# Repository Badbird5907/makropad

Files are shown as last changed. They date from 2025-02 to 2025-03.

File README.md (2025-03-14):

# Makropad

Makropad is my attempt at a custom macropad, inspired by the [Stream Deck Plus](https://www.elgato.com/ca/en/p/stream-deck-plus-black).
It uses Kaith Choc v2 switches, 2 encoders, powered by a RP2040.

A user-friendly BOM can be found [here](https://github.com/Badbird5907/makropad/blob/master/PCB/BOM.md)

## Features
- 2 rotary encoders
- 10 backlit keys
- 128x32 OLED display

## Screenshots
Case

Schematic

PCB

3D Renders of the Cherry MX switch version (made with Shapr3D):

Shapr Image-2025-02-09 170116

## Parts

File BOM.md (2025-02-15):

# Makropad BOM

| Quantity | Component Description |
|---|---|
| 10x | Kailh choc v2 switches (or any other choc v2 switch) |
| 10x | Reverse-mounted SK6812MINI-E SMD LEDs |
| 12x | SMD Diodes (1N4148W) |
| 6x | Normal front-mounted SK6812-MINI SMD LEDs (SK6812mini-012) |
| 2x | EC11 Rotary encoders |
| 1x | 0.91" OLED display |
| 1x | Seeed Studio XIAO RP2040 |
| 6x | 10kΩ SMD 1206 resistors |
| 16x | 100nF SMD 1206 capacitors |
| 1x | PCF8574A I2C I/O expander |
| 5x | M3 hex nuts |
| 5x | M3x5mx4mm heatset inserts |
| 5x | M3x16mm screws |

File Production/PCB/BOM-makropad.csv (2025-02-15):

Comment | Designator | Footprint | LCSC | Quantity
RotaryEncoder_Switch | SW11 | encoder | C143788 | 1
10k | R1,R2 | R_1206_3216Metric | C17902 | 2
0.1uF | C1,C10,C11,C12,C13,C14,C15,C16,C2,C3,C4,C5,C6,C7,C8,C9 | C_1206_3216Metric | C24497 | 16
SK6812 | D23,D24,D25,D26,D27,D28 | LED_SK6812MINI_PLCC4_3.5x3.5mm_P1.75mm | C2886570 | 6
D | D1,D10,D11,D12,D2,D3,D4,D5,D6,D7,D8,D9 | D_SOD-123 | C81598 | 12
PCF8574A | U1 | SOIC127P1032X265-16N | C86832 | 1
SW_Push_45deg | SW4 | SW_Kailh_Choc_V2 |  | 1
SW_Push_45deg | SW10 | SW_Kailh_Choc_V2 |  | 1
SW_Push_45deg | SW1 | SW_Kailh_Choc_V2 |  | 1
OLED_DISPLAY | J1 | SSD1306-0.91-OLED-4pin-128x32 |  | 1
RotaryEncoder_Switch | SW12 | encoder |  | 1
SW_Push_45deg | SW6 | SW_Kailh_Choc_V2 |  | 1
SW_Push_45deg | SW2 | SW_Kailh_Choc_V2 |  | 1
SW_Push_45deg | SW7 | SW_Kailh_Choc_V2 |  | 1
SW_Push_45deg | SW5 | SW_Kailh_Choc_V2 |  | 1
SW_Push_45deg | SW8 | SW_Kailh_Choc_V2 |  | 1
Conn_01x04 | J2 | 4pin |  | 1
SW_Push_45deg | SW3 | SW_Kailh_Choc_V2 |  | 1
SW_Push_45deg | SW9 | SW_Kailh_Choc_V2 |  | 1
SK6812 | D19 | SK6812MINI-E |  | 1
SK6812 | D21 | SK6812MINI-E |  | 1
SK6812 | D16 | SK6812MINI-E |  | 1
SK6812 | D20 | SK6812MINI-E |  | 1
SK6812 | D18 | SK6812MINI-E |  | 1
SK6812 | D14 | SK6812MINI-E |  | 1
SK6812 | D13 | SK6812MINI-E |  | 1
SK6812 | D17 | SK6812MINI-E |  | 1
SK6812 | D15 | SK6812MINI-E |  | 1
MOUDLE-SEEEDUINO-XIAO | U2 | XIAO-Generic-Hybrid-14P-2.54-21X17.8MM |  | 1
SK6812 | D22 | SK6812MINI-E |  | 1

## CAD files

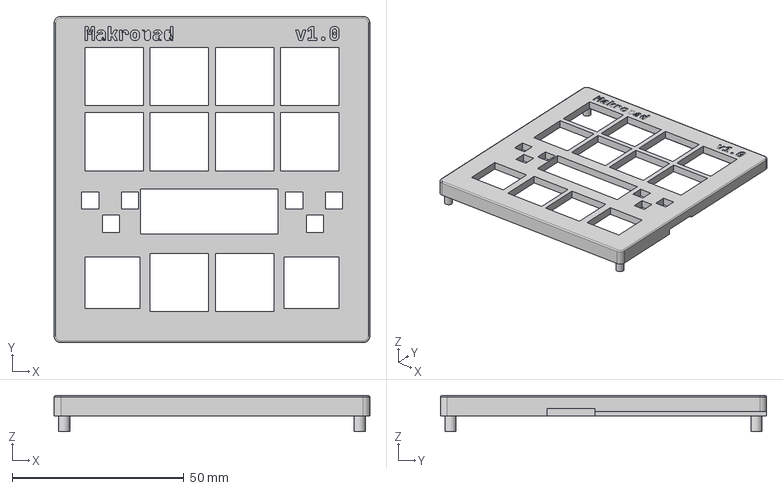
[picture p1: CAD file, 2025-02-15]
CAD/top.step
92.0 x 95.0 x 10.5 mm

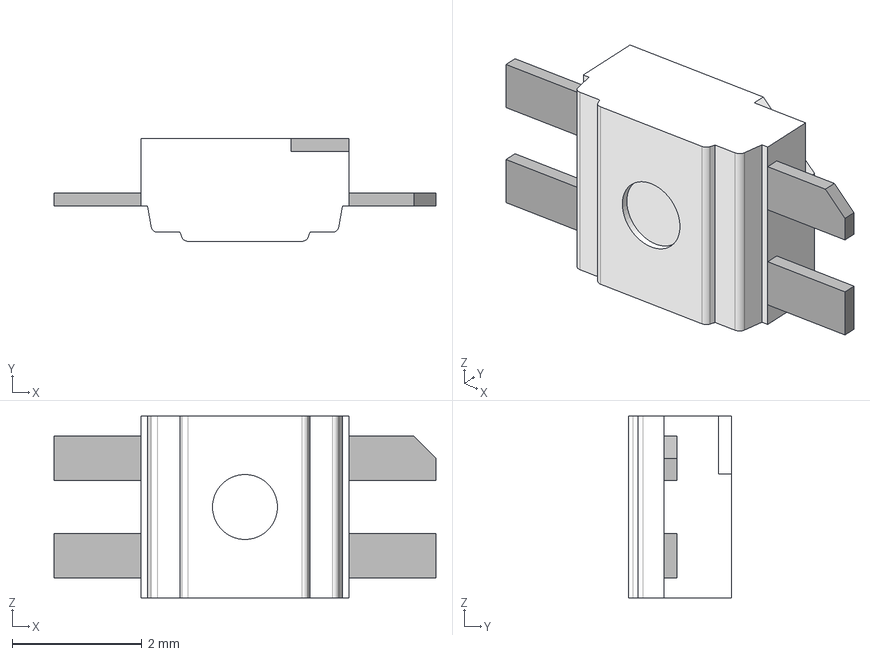
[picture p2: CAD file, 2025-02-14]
PCB/Components/neopixel.petty/SK6812MINI-E.step
5.88 x 1.58 x 2.80 mm

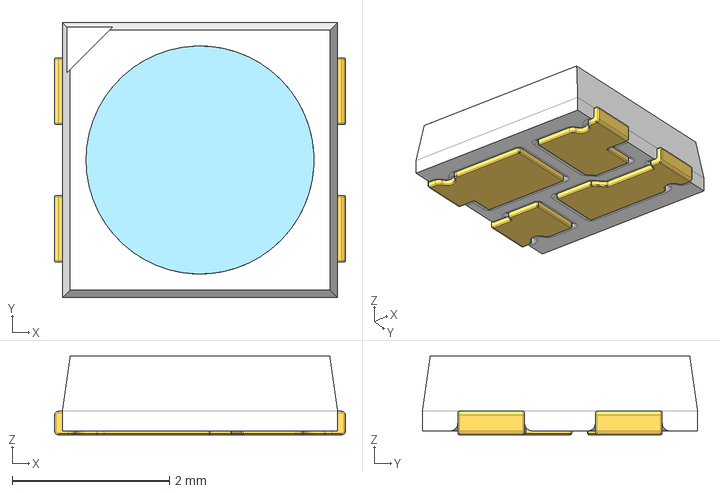
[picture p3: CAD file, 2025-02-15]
PCB/Components/SK6812_FRONT.stp
3.70 x 3.50 x 1.00 mm

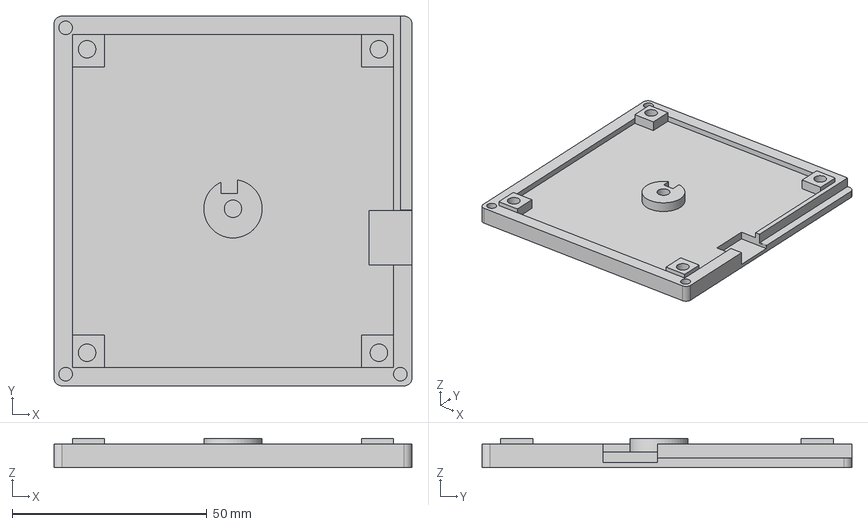
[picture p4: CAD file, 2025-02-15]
Production/3D Print/bottom.step
92.0 x 95.0 x 7.50 mm

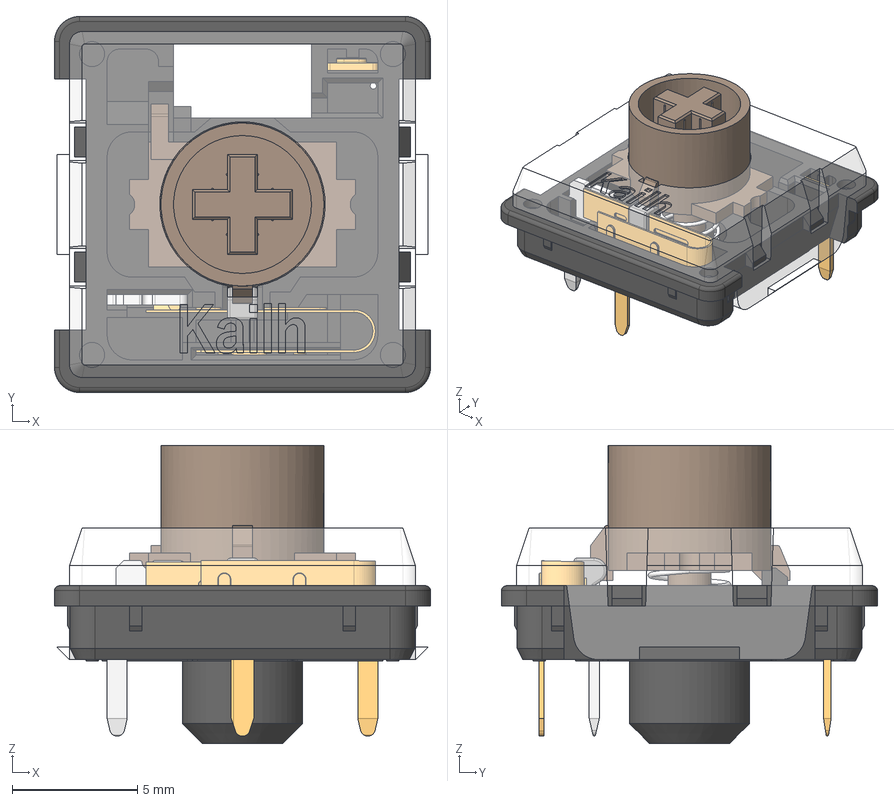
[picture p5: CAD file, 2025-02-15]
PCB/Components/choc-brown.step
15.0 x 15.0 x 11.9 mm
bottom
contact
top
stem_tactile
pin1
pin2
pin3
shrunken_spring

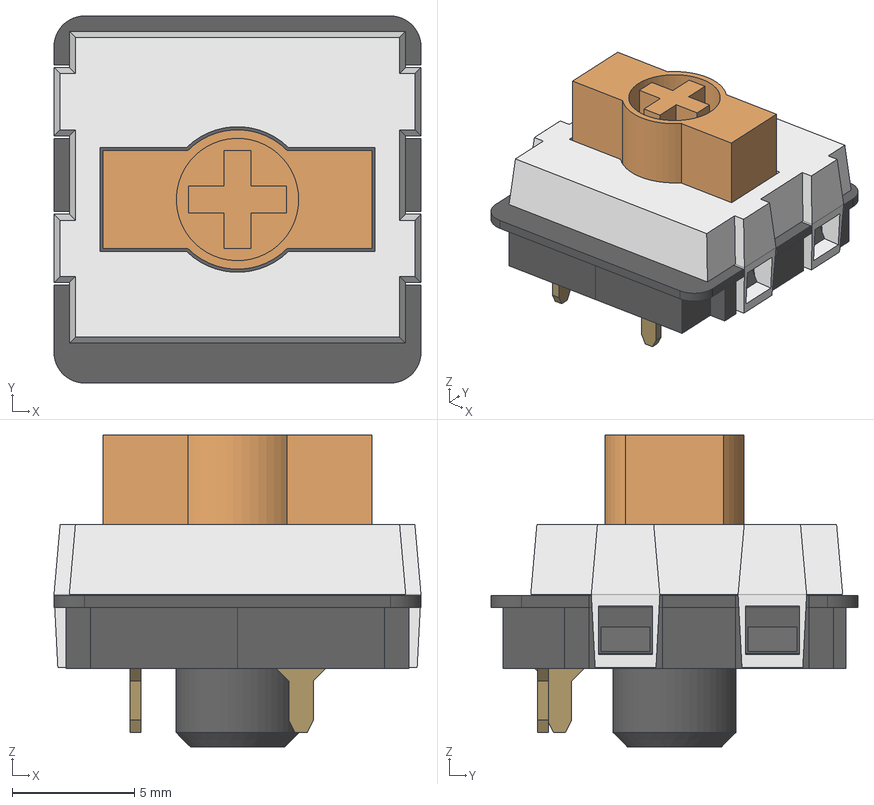
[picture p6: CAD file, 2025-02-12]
PCB/Components/Gateron KS-33.step
15.0 x 15.0 x 12.8 mm
Base
Stem
Cap
PinA
PinB

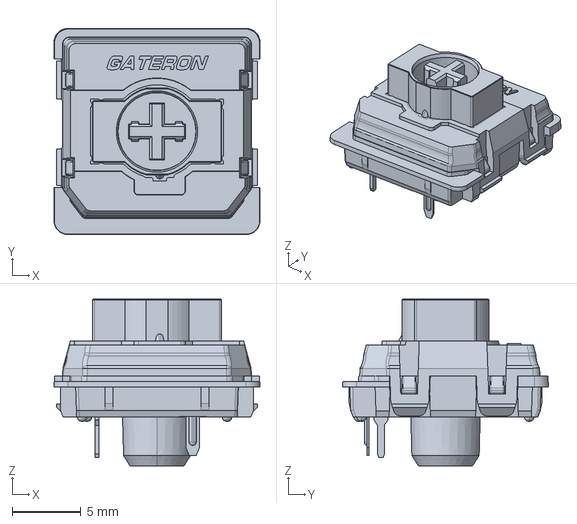
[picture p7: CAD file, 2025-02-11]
PCB/Components/Gateron Low Profile Switch 2.0.stp
15.0 x 15.0 x 12.1 mm

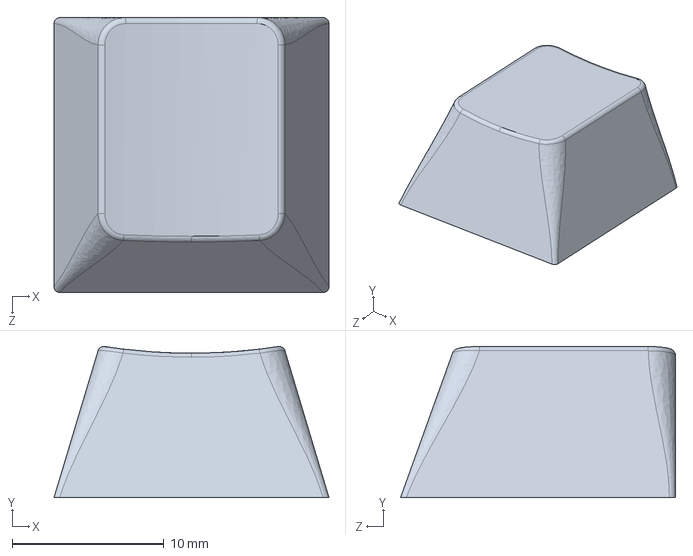
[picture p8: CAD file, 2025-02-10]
PCB/Components/r1_100.STEP
18.1 x 9.95 x 18.1 mm

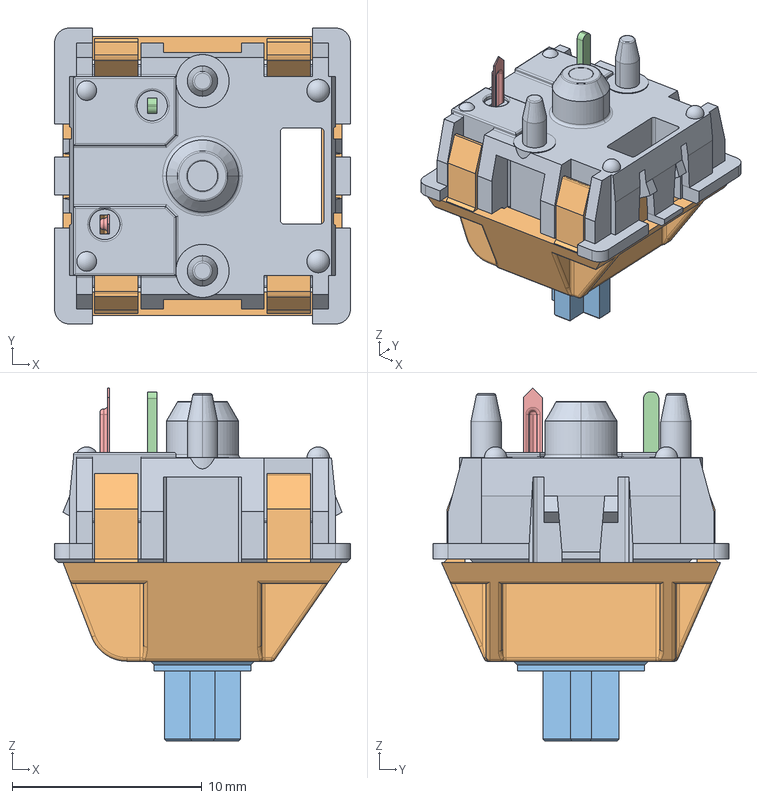
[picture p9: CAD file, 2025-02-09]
PCB/Components/CherryMX.stp
15.6 x 15.6 x 18.6 mm
MX_DOWN
MX_UP
UP_MX
MX_PIN
MX_SPRING
MX_CLICK

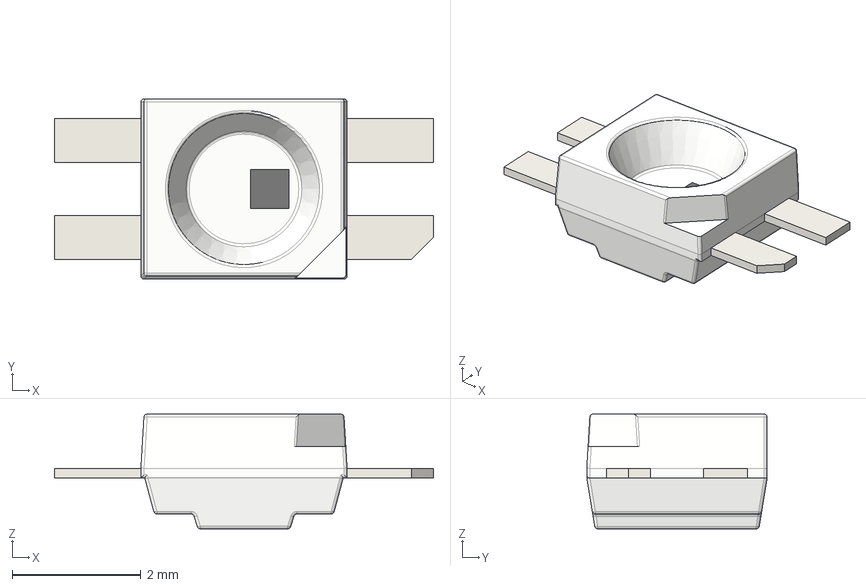
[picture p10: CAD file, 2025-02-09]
PCB/Components/LED_SK6812MINI-E.step
5.88 x 2.80 x 1.78 mm

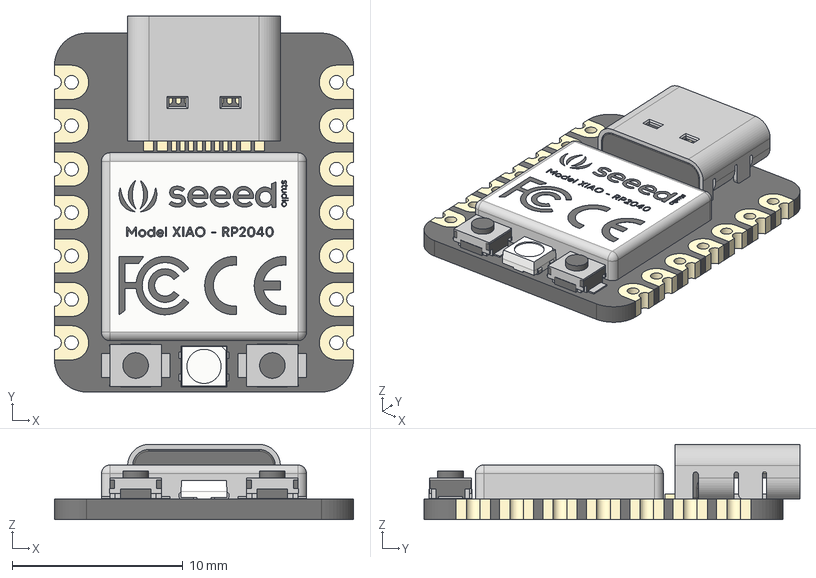
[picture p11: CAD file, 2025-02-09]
PCB/Components/Seeed Studio XIAO RP2040 v26.step
17.5 x 22.0 x 4.40 mm
type-c v2
smd_button v3
DOUT
DIN
VSS
VDD
smd_button v3(Mirror)

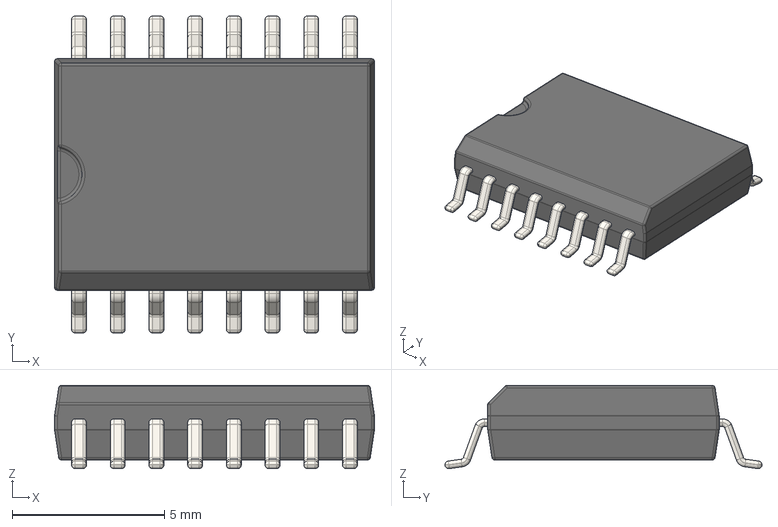
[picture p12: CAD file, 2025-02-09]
PCB/Components/SOT162-1.step
10.5 x 10.4 x 2.73 mm

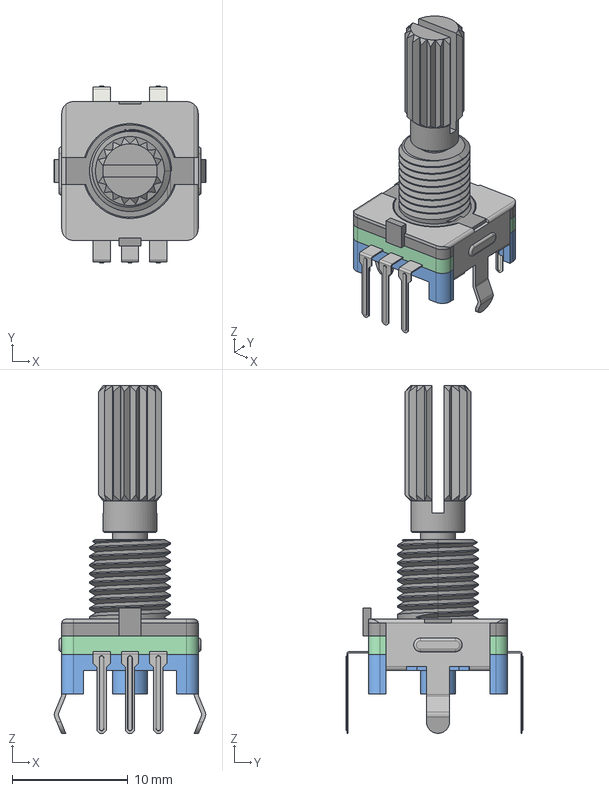
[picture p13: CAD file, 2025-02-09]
PCB/Components/EC11_Rotary_Encoder_Switched.step
13.1 x 15.3 x 30.1 mm

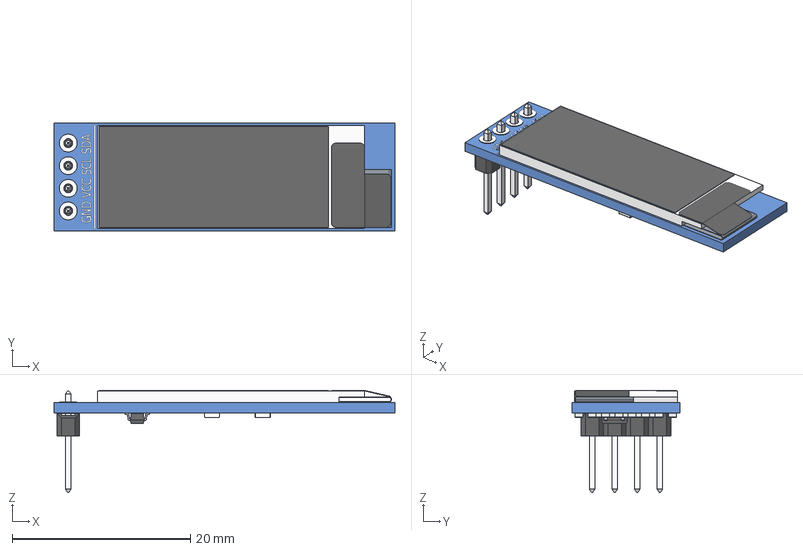
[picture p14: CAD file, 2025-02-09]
PCB/Components/OLED_0.91_128x32.stp
38.3 x 12.1 x 11.5 mm
OLED_0.91_128x32
Pin Header 4 x 1 TH 2.54mm Pitch
RESC-0603 x 13
2SD0601A

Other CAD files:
PCB/Components/N0016A.stp
PCB/Components/PCF8574A_SMD.step

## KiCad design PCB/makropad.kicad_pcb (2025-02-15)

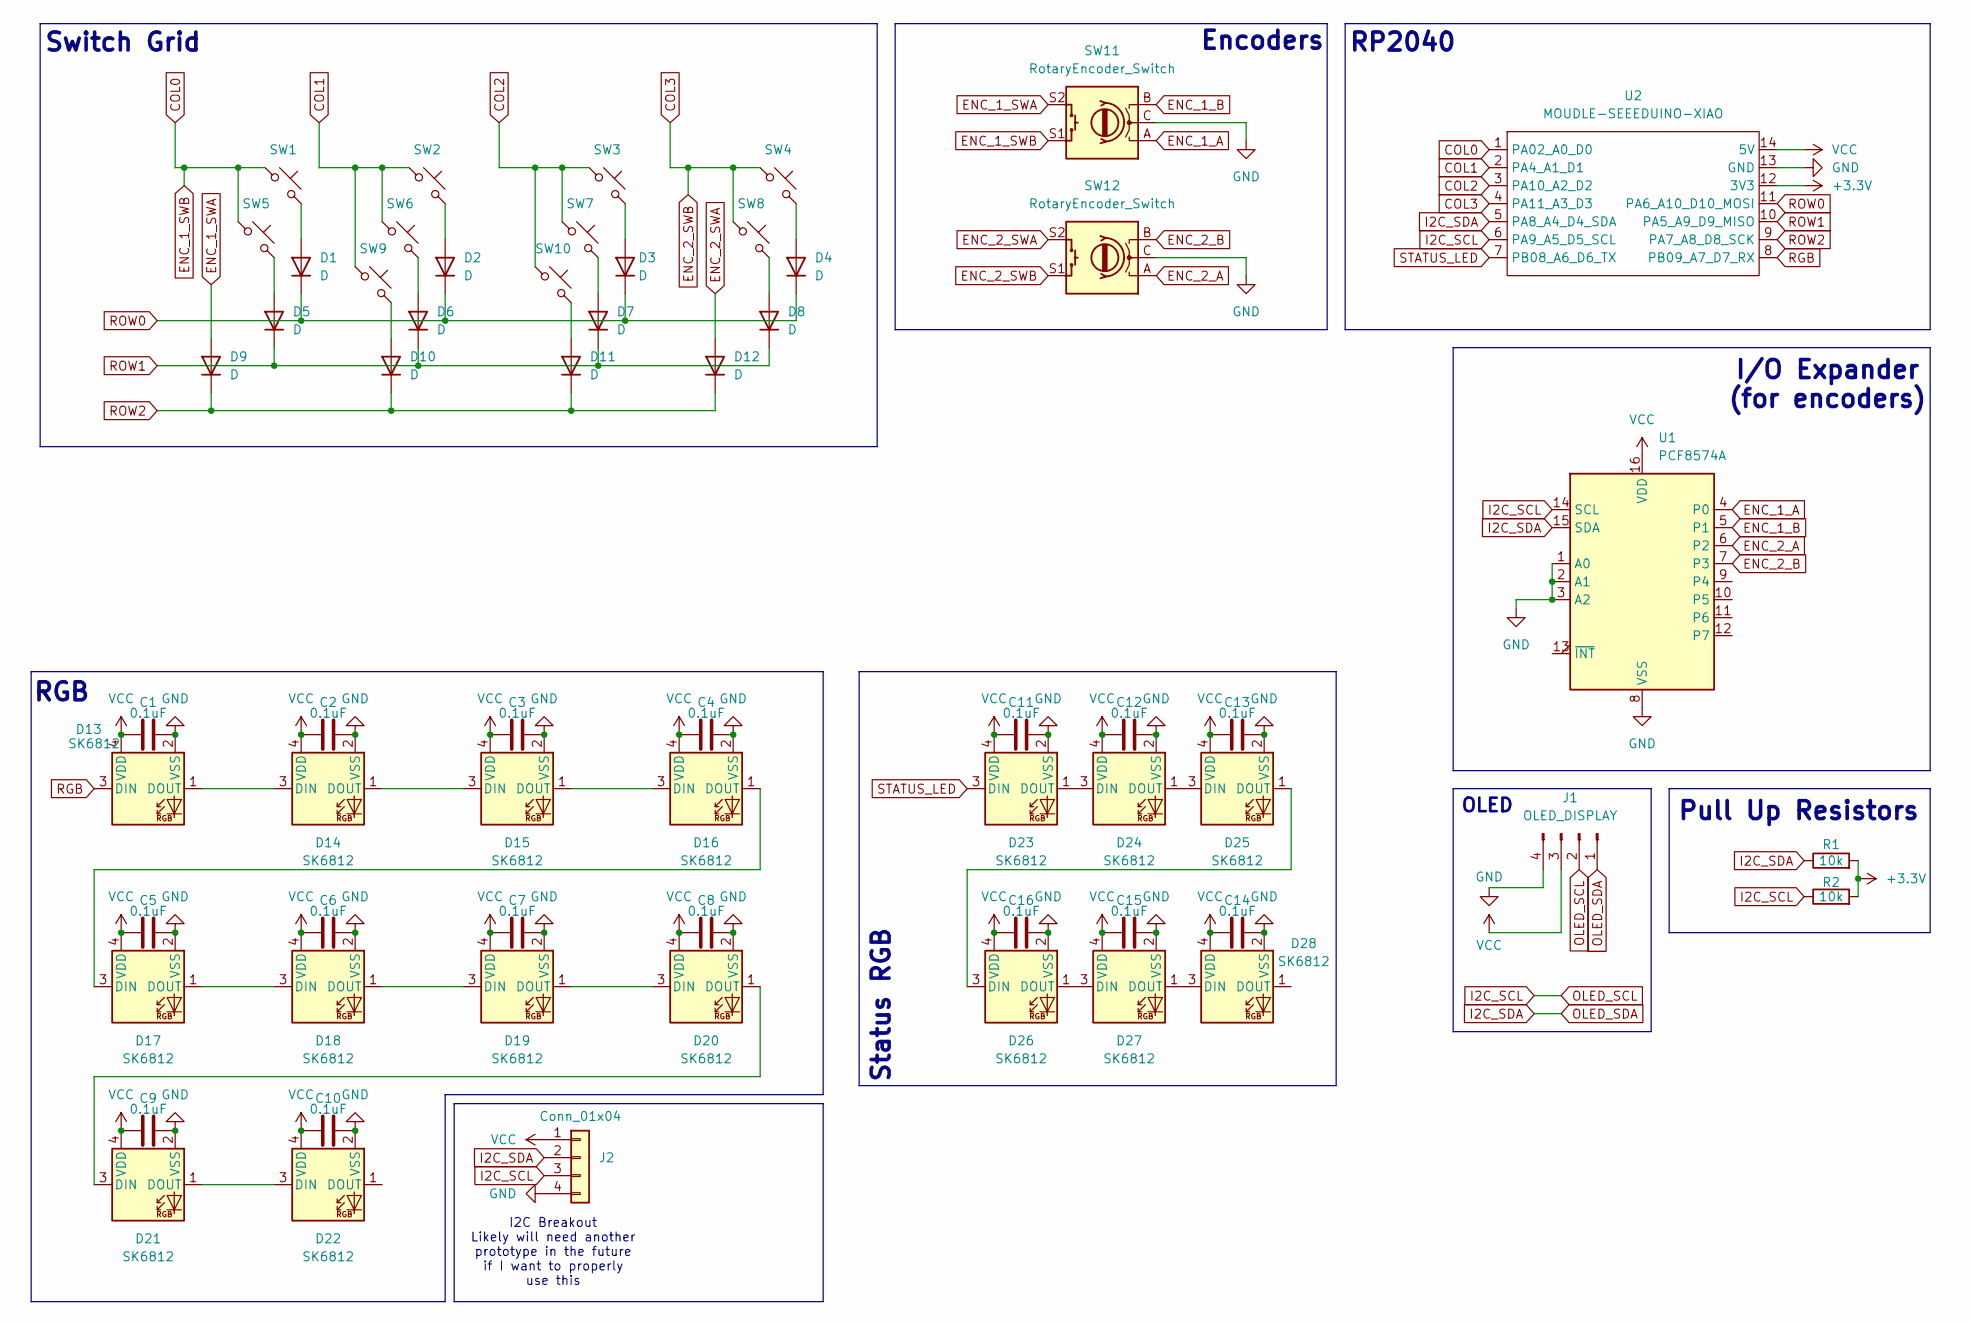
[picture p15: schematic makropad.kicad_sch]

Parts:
C1, C2, C3, C4, C5, C6, C7, C8, C9, C10, C11, C12, C13, C14, C15, C16: 0.1uF; C_1206_3216Metric
D1, D2, D3, D4, D5, D6, D7, D8, D9, D10, D11, D12: D; D_SOD-123
D13, D14, D15, D16, D17, D18, D19, D20, D21, D22: SK6812; SK6812MINI-E
D23, D24, D25, D26, D27, D28: SK6812; LED_SK6812MINI_PLCC4_3.5x3.5mm_P1.75mm
J1: OLED_DISPLAY; SSD1306-0.91-OLED-4pin-128x32
J2: Conn_01x04; 4pin
R1, R2: 10k; R_1206_3216Metric
SW1, SW2, SW3, SW4, SW5, SW6, SW7, SW8, SW9, SW10: SW_Push_45deg; SW_Kailh_Choc_V2
SW11, SW12: RotaryEncoder_Switch; encoder
U1: PCF8574A; SOIC127P1032X265-16N
U2: MOUDLE-SEEEDUINO-XIAO; XIAO-Generic-Hybrid-14P-2.54-21X17.8MM

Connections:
+3.3V: R1.2, R2.2, U2.12 (3V3)
COL0: SW1.1, SW5.1, SW11.S1, U2.1 (PA02_A0_D0)
COL1: SW2.1, SW6.1, SW9.1, U2.2 (PA4_A1_D1)
COL2: SW3.1, SW7.1, SW10.1, U2.3 (PA10_A2_D2)
COL3: SW4.1, SW8.1, SW12.S1, U2.4 (PA11_A3_D3)
ENC_1_A: SW11.A, U1.4 (P0)
ENC_1_B: SW11.B, U1.5 (P1)
ENC_1_SWA: D9.2 (A), SW11.S2
ENC_2_A: SW12.A, U1.6 (P2)
ENC_2_B: SW12.B, U1.7 (P3)
ENC_2_SWA: D12.2 (A), SW12.S2
GND: C1.2, C2.2, C3.2, C4.2, C5.2, C6.2, C7.2, C8.2, C9.2, C10.2, C11.2, C12.2, C13.2, C14.2, C15.2, C16.2, D13.2 (VSS), D14.2 (VSS), D15.2 (VSS), D16.2 (VSS), D17.2 (VSS), D18.2 (VSS), D19.2 (VSS), D20.2 (VSS), D21.2 (VSS), D22.2 (VSS), D23.2 (VSS), D24.2 (VSS), D25.2 (VSS), D26.2 (VSS), D27.2 (VSS), D28.2 (VSS), J1.4, J2.4, SW11.C, SW12.C, U1.1 (A0), U1.2 (A1), U1.3 (A2), U1.8 (VSS), U2.13 (GND)
I2C_SCL: J1.2, J2.3, R2.1, U1.14 (SCL), U2.6 (PA9_A5_D5_SCL)
I2C_SDA: J1.1, J2.2, R1.1, U1.15 (SDA), U2.5 (PA8_A4_D4_SDA)
unnamed: D1.2 (A), SW1.2
unnamed: D2.2 (A), SW2.2
unnamed: D3.2 (A), SW3.2
unnamed: D4.2 (A), SW4.2
unnamed: D5.2 (A), SW5.2
unnamed: D6.2 (A), SW6.2
unnamed: D7.2 (A), SW7.2
unnamed: D8.2 (A), SW8.2
unnamed: D10.2 (A), SW9.2
unnamed: D11.2 (A), SW10.2
unnamed: D13.1 (DOUT), D14.3 (DIN)
unnamed: D14.1 (DOUT), D15.3 (DIN)
unnamed: D15.1 (DOUT), D16.3 (DIN)
unnamed: D16.1 (DOUT), D17.3 (DIN)
unnamed: D17.1 (DOUT), D18.3 (DIN)
unnamed: D18.1 (DOUT), D19.3 (DIN)
unnamed: D19.1 (DOUT), D20.3 (DIN)
unnamed: D20.1 (DOUT), D21.3 (DIN)
unnamed: D21.1 (DOUT), D22.3 (DIN)
unnamed: D23.1 (DOUT), D24.3 (DIN)
unnamed: D24.1 (DOUT), D25.3 (DIN)
unnamed: D25.1 (DOUT), D26.3 (DIN)
unnamed: D26.1 (DOUT), D27.3 (DIN)
unnamed: D27.1 (DOUT), D28.3 (DIN)
RGB: D13.3 (DIN), U2.8 (PB09_A7_D7_RX)
ROW0: D1.1 (K), D2.1 (K), D3.1 (K), D4.1 (K), U2.11 (PA6_A10_D10_MOSI)
ROW1: D5.1 (K), D6.1 (K), D7.1 (K), D8.1 (K), U2.10 (PA5_A9_D9_MISO)
ROW2: D9.1 (K), D10.1 (K), D11.1 (K), D12.1 (K), U2.9 (PA7_A8_D8_SCK)
STATUS_LED: D23.3 (DIN), U2.7 (PB08_A6_D6_TX)
VCC: C1.1, C2.1, C3.1, C4.1, C5.1, C6.1, C7.1, C8.1, C9.1, C10.1, C11.1, C12.1, C13.1, C14.1, C15.1, C16.1, D13.4 (VDD), D14.4 (VDD), D15.4 (VDD), D16.4 (VDD), D17.4 (VDD), D18.4 (VDD), D19.4 (VDD), D20.4 (VDD), D21.4 (VDD), D22.4 (VDD), D23.4 (VDD), D24.4 (VDD), D25.4 (VDD), D26.4 (VDD), D27.4 (VDD), D28.4 (VDD), J1.3, J2.1, U1.16 (VDD), U2.14 (5V)

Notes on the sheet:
RGB
Switch Grid
RP2040
OLED
I2C Breakout Likely will need another prototype in the future if I want to properly use this
Encoders
Status RGB
I/O Expander (for encoders)
Pull Up Resistors

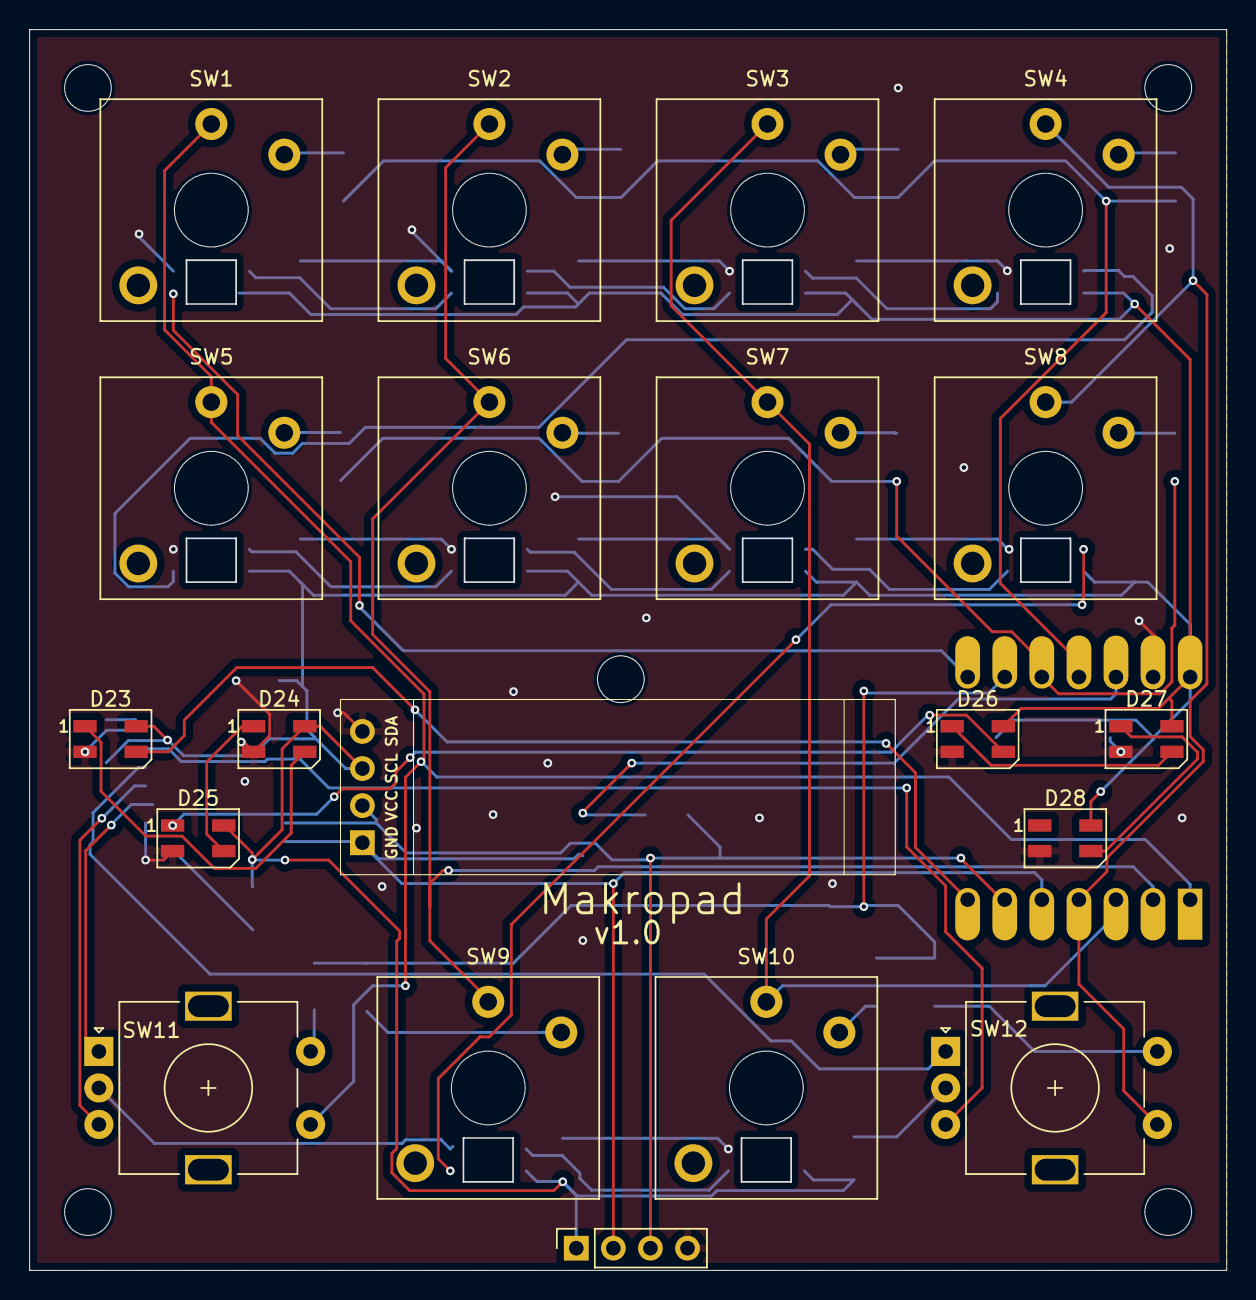
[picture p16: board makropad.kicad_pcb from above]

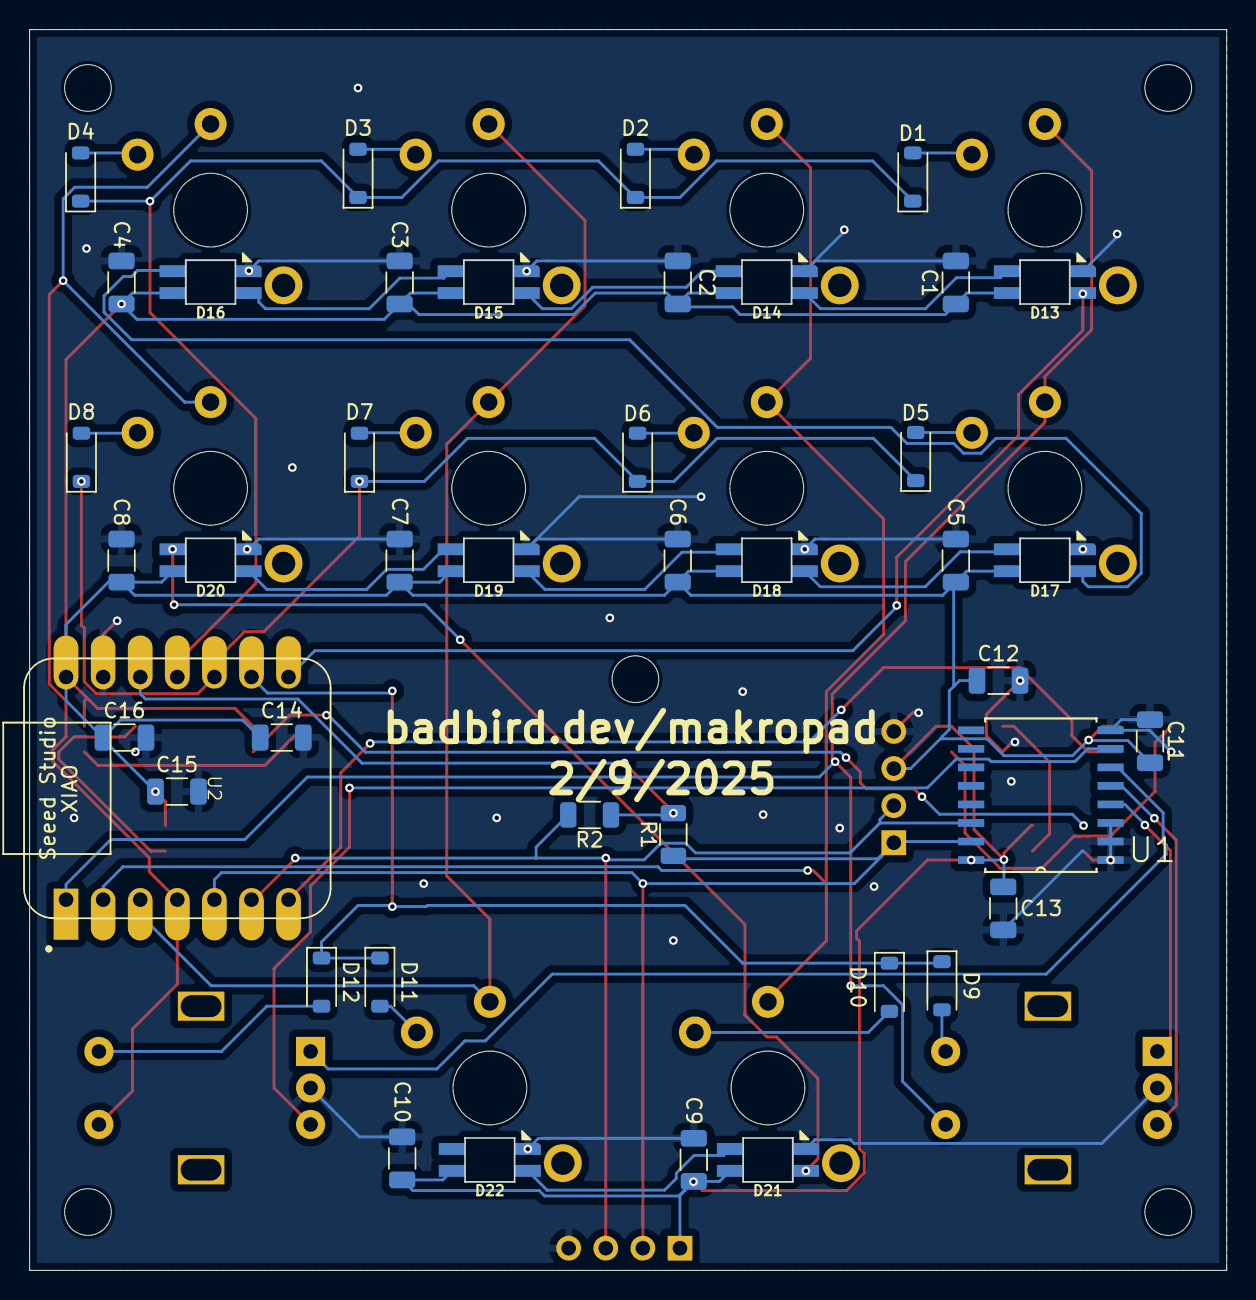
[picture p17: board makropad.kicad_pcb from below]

Board: 2 copper layers, 82.0 x 85.0 mm, 67 parts (43 on the bottom side), 44 nets.

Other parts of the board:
MH1, MH2, MH3, MH4, MH5: MountingHole_3.2mm_M3

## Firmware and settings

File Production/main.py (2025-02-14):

import board
import busio
from kmk.kmk_keyboard import KMKKeyboard
from kmk.scanners import DiodeOrientation
from kmk.keys import KC
from kmk.modules.layers import Layers
from kmk.modules.encoder import EncoderHandler
from kmk.extensions.RGB import RGB, AnimationModes
from kmk.extensions.media_keys import MediaKeys
from kmk.extensions.oled import OLED, OLED_DisplaySize
from adafruit_pcf8574 import PCF8574

i2c = busio.I2C(board.SCL, board.SDA) # init i2c
pcf = PCF8574(i2c, address=0x20)  # default PCF8574A address

keyboard = KMKKeyboard()

keyboard.col_pins = (board.D0, board.D1, board.D2, board.D3)
keyboard.row_pins = (board.D10, board.D9, board.D8)
keyboard.diode_orientation = DiodeOrientation.COL2ROW

rgb = RGB(
    pixel_pin=board.D7,
    num_pixels=10,
    animation_mode=AnimationModes.STATIC,
    val_limit=100,
    hue_default=0,
    sat_default=100,
    val_default=20,
)
keyboard.extensions.append(rgb)

oled = OLED(
    width=128,
    height=32,
    size=OLED_DisplaySize.OLED_128x32,
    flip=False
)
keyboard.extensions.append(oled)

def update_oled():
    oled.clear()
    oled.text("Makropad", 0, 0)
    oled.show()

# encoders
encoder_handler = EncoderHandler()
encoder_handler.pins = (
    # encoder 1
    ((pcf.get_pin(0), pcf.get_pin(1)), None, False),
    # encoder 2
    ((pcf.get_pin(2), pcf.get_pin(3)), None, False),
)

# encoder actions
def encoder_1_handler(keyboard, state):
    if state:
        keyboard.tap_key(KC.VOLU)
    else:
        keyboard.tap_key(KC.VOLD)

def encoder_2_handler(keyboard, state):
    if state:
        keyboard.tap_key(KC.MNXT)
    else:
        keyboard.tap_key(KC.MPRV)

encoder_handler.map = (
    ((encoder_1_handler, encoder_1_handler),),  # layer 0
    ((encoder_2_handler, encoder_2_handler),),  # layer 0
)

keyboard.modules.append(encoder_handler)
keyboard.modules.append(Layers())
keyboard.extensions.append(MediaKeys())

keyboard.keymap = [
    [   # base layer
        KC.A,    KC.B,    KC.C,    KC.D,
        KC.E,    KC.F,    KC.G,    KC.H,
        KC.NO,   KC.J,    KC.K,    KC.NO,  # NO = encoder buttons
    ]
]

if __name__ == '__main__':
    update_oled() # start oled
    keyboard.go()

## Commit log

2025-01-31 Finish pcb
    [N0016A.stp, PCF8574A_SMD.step, makropad.kicad_pcb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]
2025-02-09 feat: finish pcb placement
    [makropad.kicad_pcb, makropad.kicad_sch]
2025-02-09 feat: fully route pcb
    [makropad.kicad_pcb, makropad.kicad_sch]
2025-02-09 feat: add 3d renders
    [OLED_0.91_128x32.stp, makropad.kicad_pcb, makropad.kicad_sch]
2025-02-09 chore: move kicad files to pcb folder
    [N0016A.stp, OLED_0.91_128x32.stp, PCF8574A_SMD.step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]
2025-02-09 feat: select jlc parts
    [makropad.kicad_pcb]
2025-02-09 feat: switch to SOD-123 diodes
    [makropad.kicad_pcb, makropad.kicad_sch]
2025-02-09 feat: generate production gerbers
    [BOM-makropad.csv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]
2025-02-09 feat: finish sikscreen & and pcb prod files
    [makropad-CuBottom.gbr, makropad-CuTop.gbr, makropad-EdgeCuts.gbr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]
2025-02-09 feat: finalize pcb design and 3d renders
    [CherryMX.stp, EC11_Rotary_Encoder_Switched.step, LED_SK6812MINI-E.step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]
2025-02-09 fix: led spacing on bottom switches
    [makropad.kicad_pcb]
2025-02-10 feat: add bom
2025-02-10 feat: add mounting holes and move around some components & silkscreen
    [makropad.kicad_pcb, r1_100.STEP]
2025-02-11 feat: switch to gateron low profile
    [Gateron Low Profile Switch 2.0.stp, makropad.kicad_pcb, makropad.kicad_sch]
2025-02-11 feat: add mounting holes for new design
    [makropad.kicad_pcb]
2025-02-13 feat: pull up i2c lines to 3.3v and remove encoder pull ups
    [BOM-makropad.csv, case bottom.step, case bottom.stl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]
2025-02-14 finally finish up pcb and fix led wiring
    [BOM-makropad.csv, SK6812MINI-E.step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]
2025-02-14 generate production files
    [BOM-makropad.csv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]
2025-02-14 fix: clarify gateron switches in bom
2025-02-14 fix some stuff + firmware
    [makropad.kicad_pcb, makropad.kicad_sch]
2025-02-14 Generate all production files
    [BOM-makropad.csv, makropad.kicad_pcb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]
2025-02-15 feat: switch to choc v2 switches
    [BOM-makropad.csv, SK6812_FRONT.stp, bottom.step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]
2025-02-15 Update production files
    [makropad.kicad_pcb]
